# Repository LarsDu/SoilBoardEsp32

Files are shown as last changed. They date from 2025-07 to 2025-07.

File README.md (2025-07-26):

# SoilBoardEsp32

A custom PCB for the ESP32-S3-WROOM-1 designed for WiFi enabled and battery powered automated plant watering.

Could also be used to control a dual propeller drone.

Certain parts of the circuit schematic were sourced/adapted from the [LiteWing](https://github.com/Circuit-Digest/LiteWing/tree/main) open source drone project.

Setup with:
 - 2 Screw terminals for 3-4V DC water pumps
 - 2 Capacitative soil moisture sensors
 - Either a DHT-40 or AHT-40 temperature/humidity sensor
 - An optional TFT display
 - 2 optional servo headers
 - An optional ping sensor header for water level detection

This is my first-time PCB design and assembly attempt. This repo may be updated as I make more progress on actual construction.

# Getting started

Board schematics can be opened in KiCad under [`hardware/soilboard/soilboard.kicad_pro`](hardware/soilboard/soilboard.kicad_pro).

Gerber files for each production version can be found under [`hardware/soilboard/production/`](hardware/soilboard/production/)

## Images

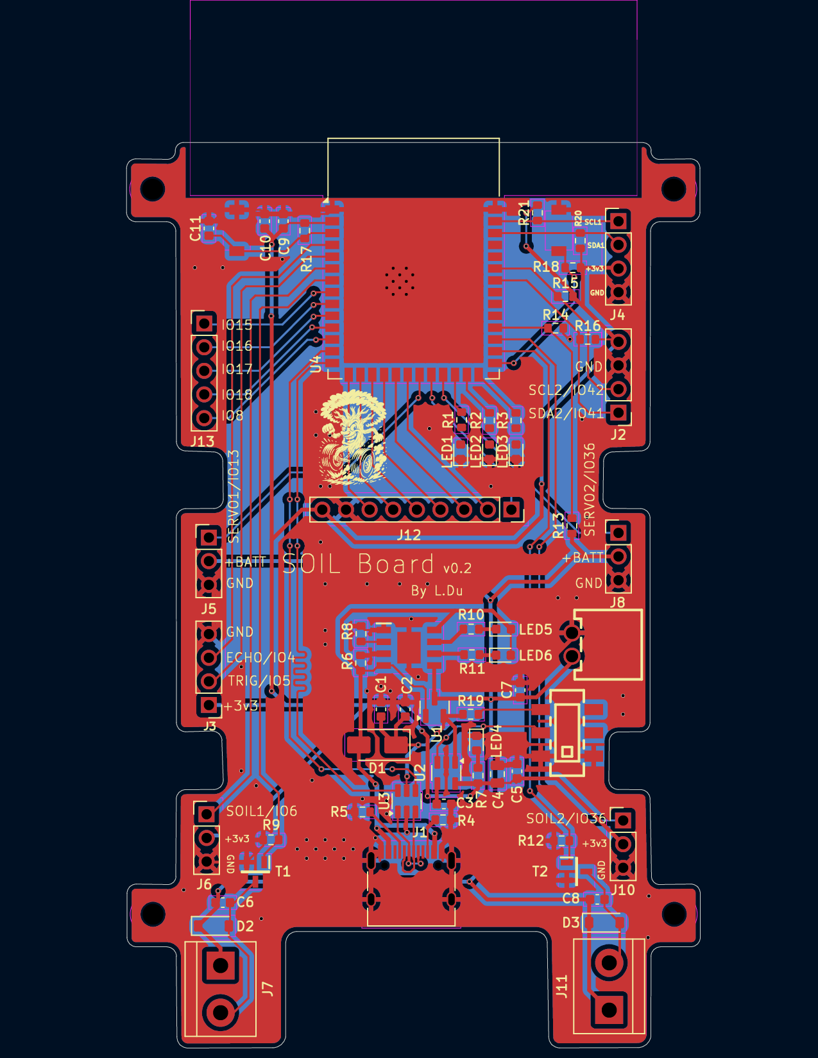
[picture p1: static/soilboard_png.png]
PCB appearance


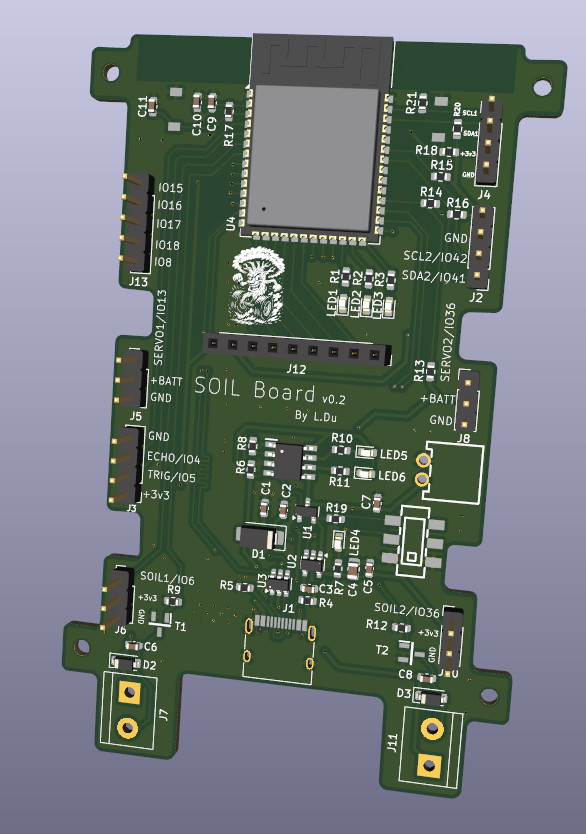
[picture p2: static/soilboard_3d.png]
PCB 3D Render


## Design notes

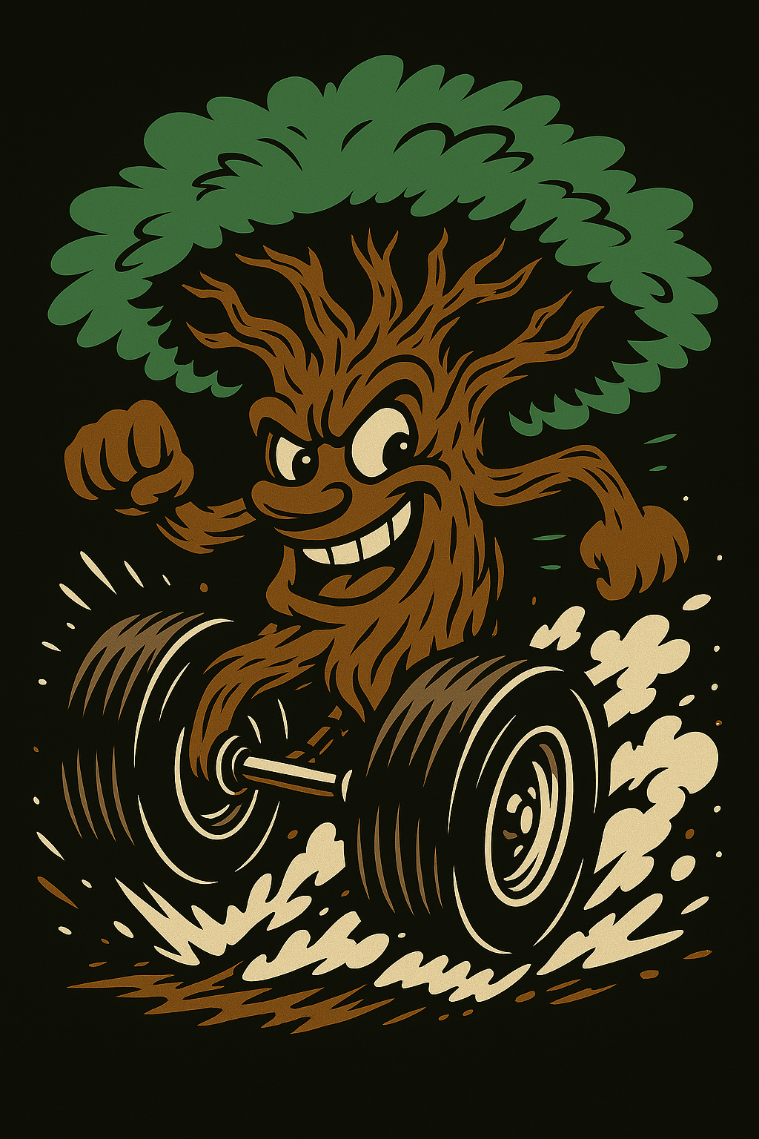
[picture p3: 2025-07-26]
hardware/decals/soilguy.png

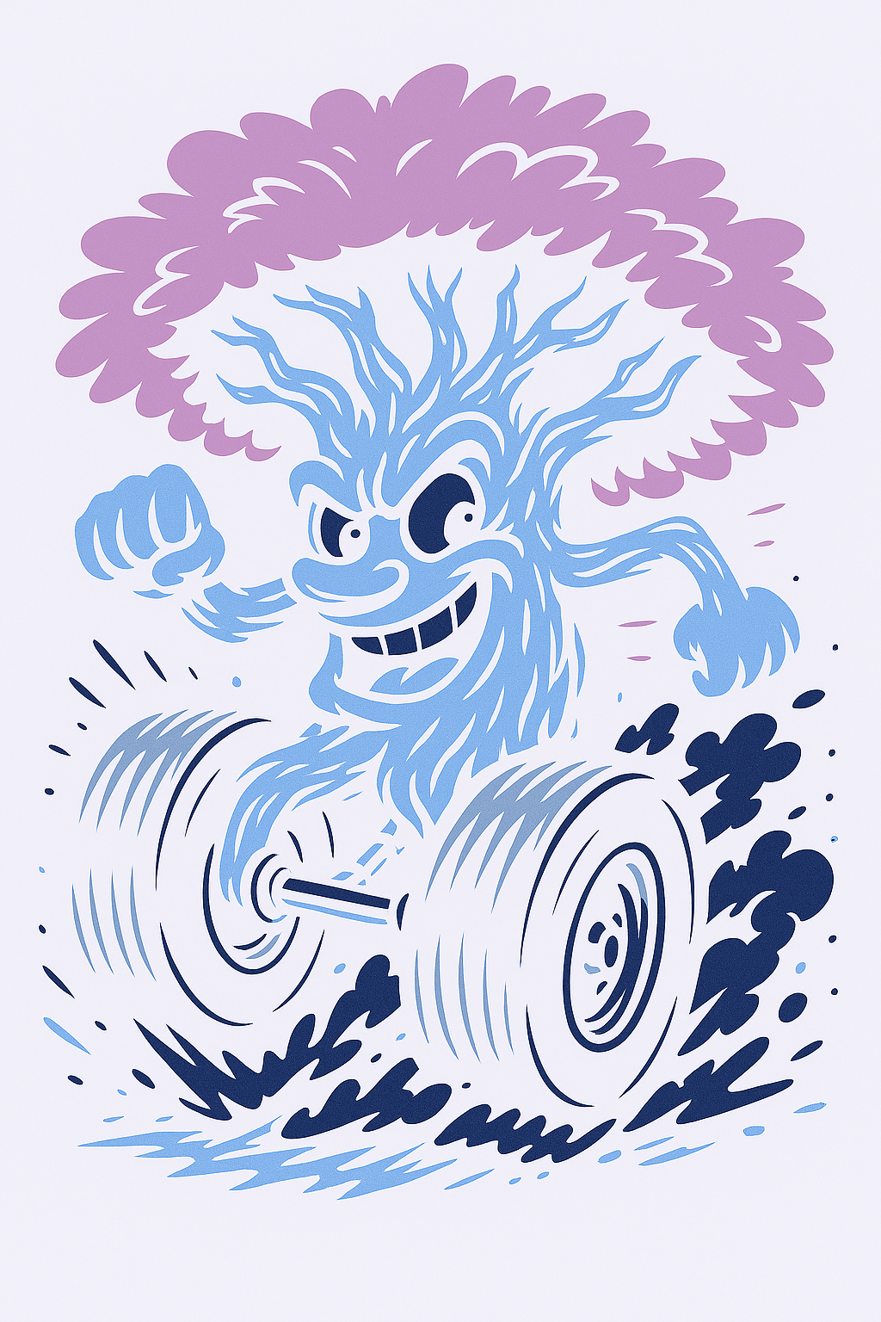
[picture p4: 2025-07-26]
hardware/decals/soilguy_inverted.png

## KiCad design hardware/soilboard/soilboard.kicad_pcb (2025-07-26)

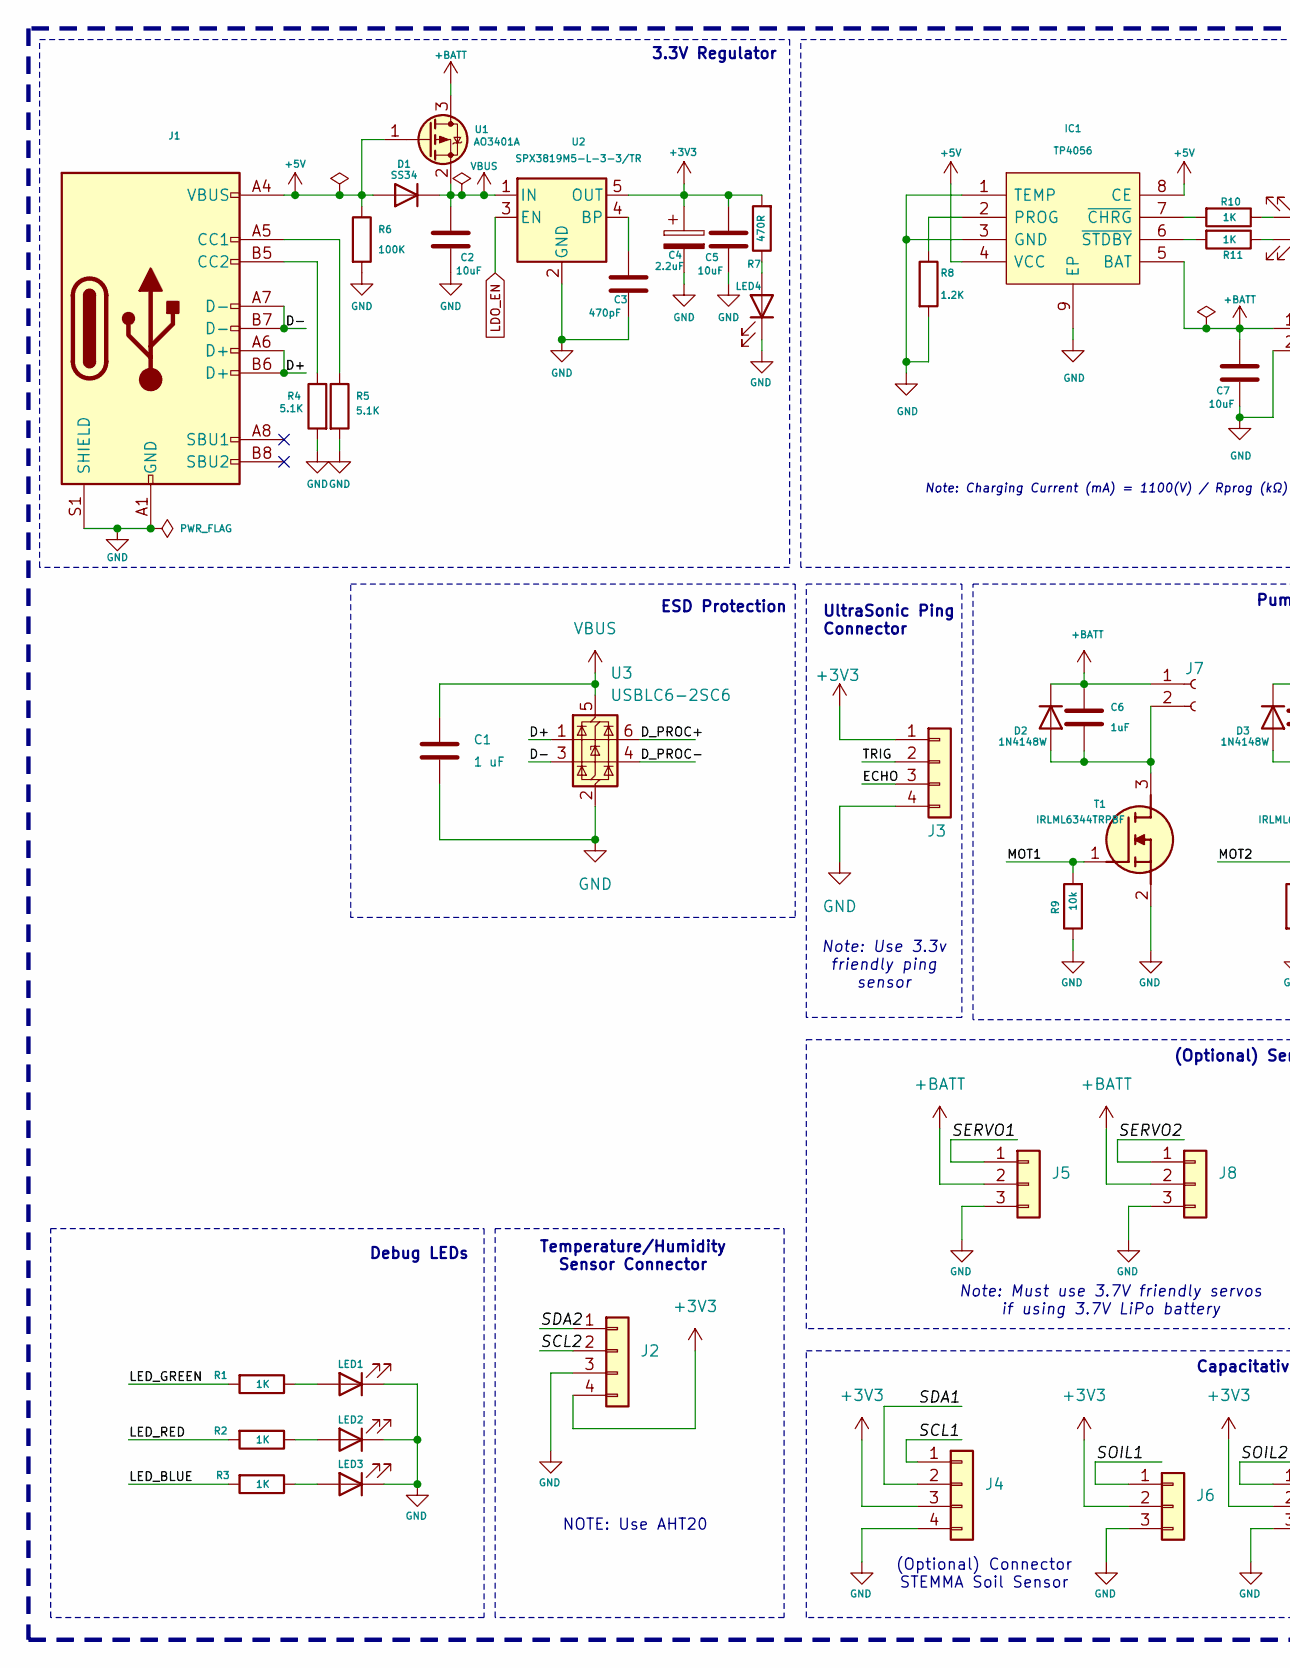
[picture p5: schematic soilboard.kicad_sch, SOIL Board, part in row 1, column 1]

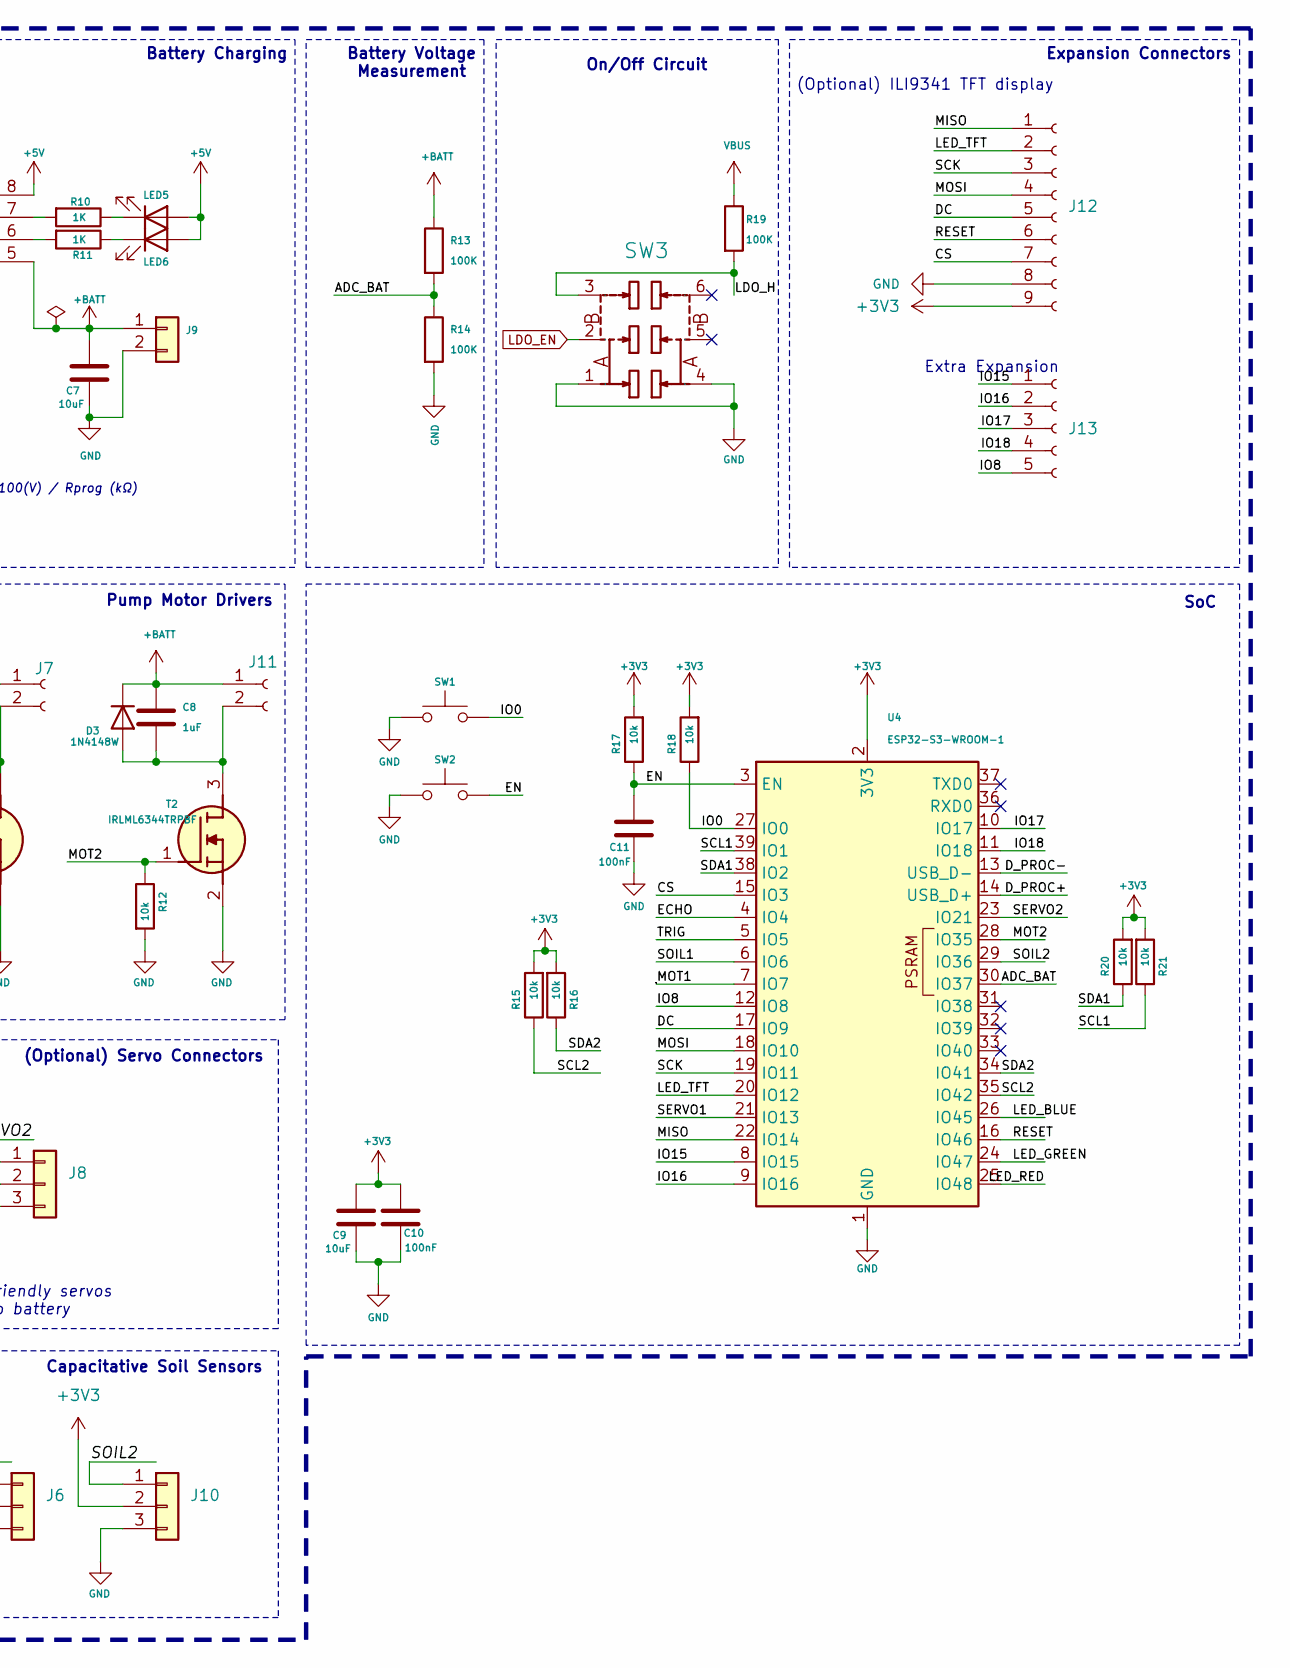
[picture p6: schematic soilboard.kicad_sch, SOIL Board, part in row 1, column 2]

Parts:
C1: 1 uF; C_0603_1608Metric
C2, C5, C7, C9: 10uF; C_0603_1608Metric; MFR.Part # CL10A106KP8NNNC; LCSC Part # C19702
C3: 470pF; C_0603_1608Metric; MFR.Part # 0603B471K500NT; LCSC Part # C1620
C4: 2.2uF; C_0805_2012Metric; MFR.Part # TCC0805X7R225M250FT; LCSC Part # C5448893
C6, C8: 1uF; C_0603_1608Metric; MFR.Part # CL10A105KB8NNNC; LCSC Part # C15849
C10, C11: 100nF; C_0603_1608Metric; MFR.Part # CC0603KRX7R9BB104; LCSC Part # C14663
D1: SS34; D_SMA; MFR.Part # SS34; LCSC Part # C8678
D2, D3: 1N4148W; D_SOD-123; MFR.Part # 1N4148W; LCSC Part # C81598
IC1: TP4056; SOIC127P600X175-9N; MFR.Part # TP4056; LCSC Part # C20199357
J1: USB_C_Receptacle_USB2.0; USB_C_Receptacle_HRO_TYPE-C-31-M-12; MFR.Part # USB-TYPE-C-018; LCSC Part # C2927038
J2: Temp_01x04; PinHeader_1x04_P2.54mm_Vertical
J3: Ping_01x04; PinHeader_1x04_P2.54mm_Vertical
J4: Stemma_01x04; PinHeader_1x04_P2.54mm_Vertical
J5, J6, J8, J10: Conn_01x03; PinHeader_1x03_P2.54mm_Vertical
J7, J11: Conn_01x02_Socket; TerminalBlock_bornier-2_P5.08mm
J9: JST XH 2P 2.50mm SMD Hoz; CONN-TH_2P-P2.50_XH-2AW; MFR.Part # XH-2AW; LCSC Part # C33132
J12: Conn_01x09_Socket; PinSocket_1x09_P2.54mm_Vertical
J13: Extra_01x04_Socket; PinHeader_1x05_P2.54mm_Vertical
LED1: LED_Green; LED_0603_1608Metric; MFR.Part # LTST-C193TGKT-5A; LCSC Part # C12065
LED2, LED4, LED5: LED_Red; LED_0603_1608Metric; MFR.Part # KT-0603R; LCSC Part # C2286
LED3, LED6: LED_Blue; LED_0603_1608Metric; MFR.Part # KT-0603B; LCSC Part # C2288
R1, R2, R3, R10, R11: 1K; R_0603_1608Metric; MFR.Part # 0603WAF1001T5E; LCSC Part # C21190
R4, R5: 5.1K; R_0603_1608Metric; MFR.Part # 0603WAF5101T5E; LCSC Part # C23186
R6, R13, R14, R19: 100K; R_0603_1608Metric; MFR.Part # 0603WAF1003T5E; LCSC Part # C25803
R7: 470R; R_0603_1608Metric; MFR.Part # 0603WAF4700T5E; LCSC Part # C23179
R8: 1.2K; R_0603_1608Metric; MFR.Part # 0603WAF1201T5E; LCSC Part # C22765
R9, R12, R15, R16, R17, R18, R20, R21: 10k; R_0603_1608Metric; MFR.Part # 0603WAF1002T5E; LCSC Part # C25804
SW1, SW2: Tactile Switch 3x4x2; Tactile 3x4x2mm TS-A010; MFR.Part # TS-KG88C-ART25F; LCSC Part # C2874433
SW3: MST22D18G2_125; SW-SMD_MST22D18G2; MFR.Part # MST22D18G2 125; LCSC Part # C2906280
T1, T2: IRLML6344TRPBF; SOT95P237X112-3N; MFR.Part # IRLML6344TRPBF-HXY; LCSC Part # C6285738
U1: AO3401A; SOT-23; MFR.Part # AO3401A; LCSC Part # C15127
U2: SPX3819M5-L-3-3/TR; SOT-23-5; MFR.Part # SPX3819M5-L-3-3/TR; LCSC Part # C9055
U3: USBLC6-2SC6; SOT-23-6
U4: ESP32-S3-WROOM-1; MFR.Part # ESP32-S3-WROOM-1-N8; LCSC Part # C2913198

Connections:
+3V3: C4.1, C5.1, C9.1, C10.1, J2.4, J3.1, J4.3, J6.2, J10.2, J12.9, R7.2, R15.2, R16.2, R17.2, R18.2, R20.2, R21.2, U2.5 (OUT), U4.2 (3V3)
+5V: D1.2 (A), IC1.4 (VCC), IC1.8 (CE), J1.A4 (VBUS), J1.A9 (VBUS), J1.B4 (VBUS), J1.B9 (VBUS), LED5.2 (A), LED6.2 (A), R6.1, U1.1 (G)
+BATT: C6.1, C7.1, C8.1, D2.1 (K), D3.1 (K), IC1.5 (BAT), J5.2, J7.1, J8.2, J9.1, J11.1, R13.1, U1.3 (D)
/ADC_BAT: R13.2, R14.1, U4.30 (IO37)
/CS: J12.7, U4.15 (IO3)
/D+: J1.A6 (D+), J1.B6 (D+), U3.1 (I/O1)
/D-: J1.A7 (D-), J1.B7 (D-), U3.3 (I/O2)
/DC: J12.5, U4.17 (IO9)
/D_PROC+: U3.6 (I/O1), U4.14 (USB_D+)
/D_PROC-: U3.4 (I/O2), U4.13 (USB_D-)
/ECHO: J3.3, U4.4 (IO4)
/EN: C11.1, R17.1, SW2.2, U4.3 (EN)
/IO0: R18.1, SW1.2, U4.27 (IO0)
/IO8: J13.5, U4.12 (IO8)
/IO15: J13.1, U4.8 (IO15)
/IO16: J13.2, U4.9 (IO16)
/IO17: J13.3, U4.10 (IO17)
/IO18: J13.4, U4.11 (IO18)
/LDO_H: R19.2, SW3.3
/LED_BLUE: R3.2, U4.26 (IO45)
/LED_GREEN: R1.2, U4.24 (IO47)
/LED_RED: R2.2, U4.25 (IO48)
/LED_TFT: J12.2, U4.20 (IO12)
/MISO: J12.1, U4.22 (IO14)
/MOSI: J12.4, U4.18 (IO10)
/MOT1: R9.2, T1.1 (G), U4.7 (IO7)
/MOT2: R12.1, T2.1 (G), U4.28 (IO35)
/RESET: J12.6, U4.16 (IO46)
/SCK: J12.3, U4.19 (IO11)
/SCL1: J4.1, R21.1, U4.39 (IO1)
/SCL2: J2.2, R15.1, U4.35 (IO42)
/SDA1: J4.2, R20.1, U4.38 (IO2)
/SDA2: J2.1, R16.1, U4.34 (IO41)
/SERVO1: J5.1, U4.21 (IO13)
/SERVO2: J8.1, U4.23 (IO21)
/SOIL1: J6.1, U4.6 (IO6)
/SOIL2: J10.1, U4.29 (IO36)
/TRIG: J3.2, U4.5 (IO5)
GND: C1.2, C2.2, C3.2, C4.2, C5.2, C7.2, C9.2, C10.2, C11.2, IC1.1 (TEMP), IC1.3 (GND), IC1.9 (EP), J1.A1 (GND), J1.A12 (GND), J1.B1 (GND), J1.B12 (GND), J1.S1 (SHIELD), J2.3, J3.4, J4.4, J5.3, J6.3, J8.3, J9.2, J10.3, J12.8, LED1.1 (K), LED2.1 (K), LED3.1 (K), LED4.1 (K), R4.2, R5.2, R6.2, R8.2, R9.1, R12.2, R14.2, SW1.1, SW2.1, SW3.1, SW3.4, T1.2 (S), T2.2 (S), U2.2 (GND), U3.2 (GND), U4.1 (GND), U4.40 (GND), U4.41 (GND)
LDO_EN: SW3.2, U2.3 (EN)
unnamed: C6.2, D2.2 (A), J7.2, T1.3 (D)
unnamed: C8.2, D3.2 (A), J11.2, T2.3 (D)
unnamed: IC1.2 (PROG), R8.1
unnamed: IC1.7 (~CHRG), R10.2
unnamed: IC1.6 (~STDBY), R11.2
unnamed: J1.A5 (CC1), R5.1
unnamed: J1.B5 (CC2), R4.1
unnamed: LED1.2 (A), R1.1
unnamed: LED2.2 (A), R2.1
unnamed: LED3.2 (A), R3.1
unnamed: LED4.2 (A), R7.1
unnamed: LED5.1 (K), R10.1
unnamed: LED6.1 (K), R11.1
unnamed: C3.1, U2.4 (BP)
VBUS: C1.1, C2.1, D1.1 (K), R19.1, U1.2 (S), U2.1 (IN), U3.5 (VBUS)

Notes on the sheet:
Capacitative Soil Sensors
Expansion Connectors
3.3V Regulator
SoC
Temperature/Humidity Sensor Connector
Battery Charging
(Optional) Servo Connectors
Battery Voltage Measurement
Debug LEDs
(Optional) Connector STEMMA Soil Sensor
Note: Must use 3.7V friendly servos if using 3.7V LiPo battery
UltraSonic Ping Connector
Extra Expansion
Note: Charging Current (mA) = 1100(V) / Rprog (kΩ)
Note: Use 3.3v friendly ping sensor
On/Off Circuit
(Optional) ILI9341 TFT display
NOTE: Use AHT20
Pump Motor Drivers
ESD Protection

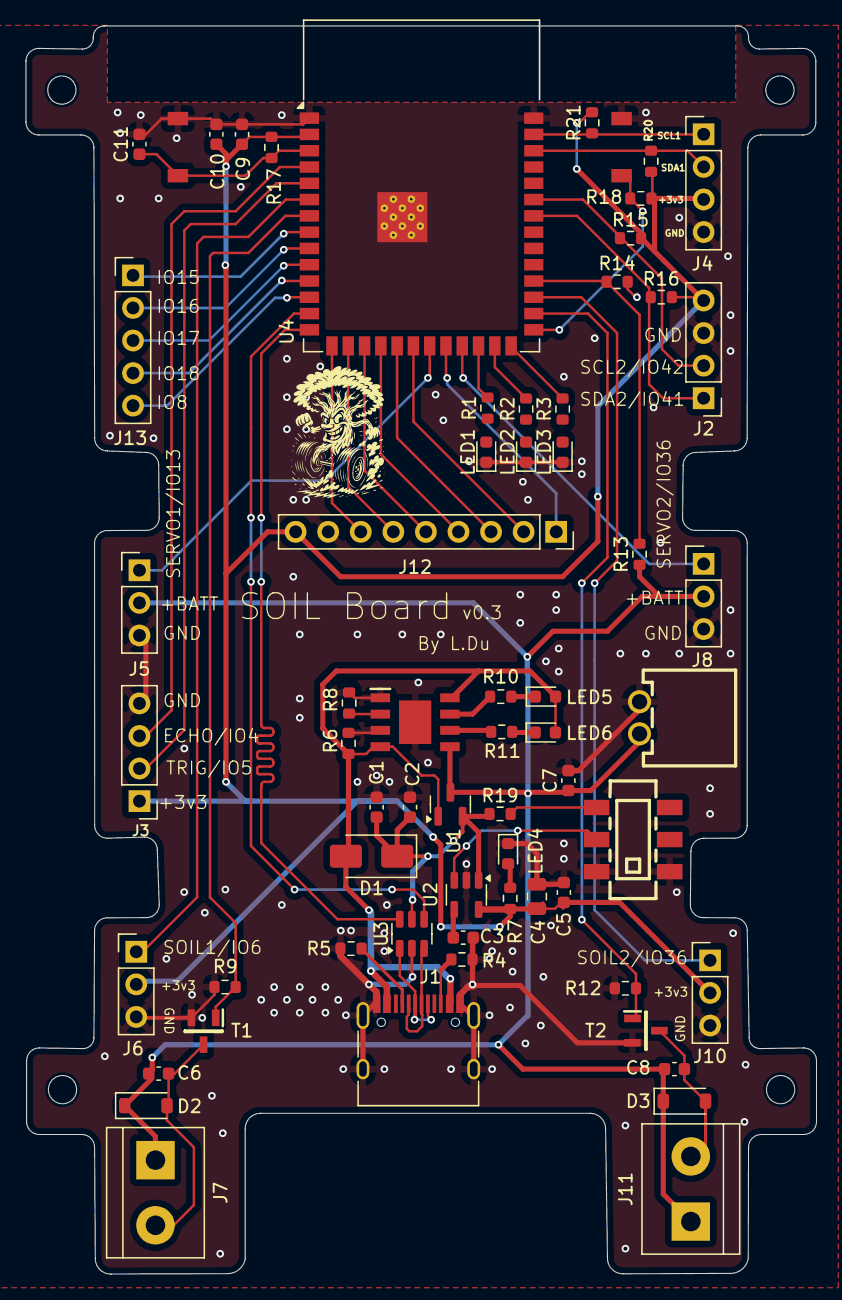
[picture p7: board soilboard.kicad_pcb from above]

Board: 2 copper layers, 61.7 x 97.3 mm, 64 parts (0 on the bottom side), 55 nets.

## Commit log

2025-07-21 First commit.
    [duo_motor_esp32.kicad_pcb, duo_motor_esp32.kicad_sch]
2025-07-26 SOILBoard v0.3 send off for manufacturing.
    [soilboard.kicad_pcb, soilboard.kicad_sch]
2025-07-26 Posible update.
    [soilboard.kicad_pcb]
